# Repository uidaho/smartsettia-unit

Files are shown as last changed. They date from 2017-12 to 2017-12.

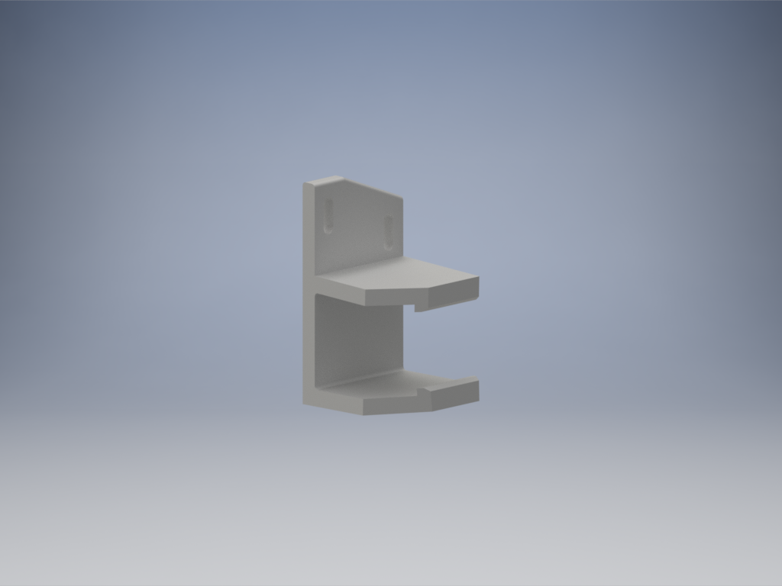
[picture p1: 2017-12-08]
3d_Parts/Limit_Switch_Brackets/Clip_Left_V2.png

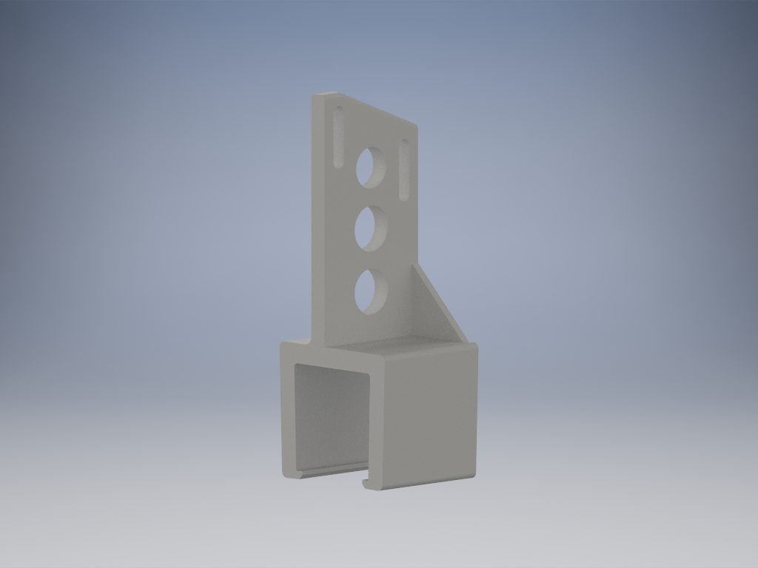
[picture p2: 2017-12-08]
3d_Parts/Limit_Switch_Brackets/Clip_Right.png

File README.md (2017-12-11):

# smartsettia-unit
Unit software for University of Idaho CS480 Capstone Project

## Instructions

### Raspberri Pi Setup
Download Raspbian 
[https://www.raspberrypi.org/downloads/raspbian/](https://www.raspberrypi.org/downloads/raspbian/)
unzip the file.

Follow these instructions
https://www.raspberrypi.org/documentation/installation/installing-images/README.md
or [download Rufus](https://rufus.akeo.ie/) and flash the image

Run `sudo raspi-config`

1. Change User Password – This step is **absolutly required!** Follow the on-screen directions to set a new password for you Pi. By default the password is set to `raspberry`, and the user is set to `pi`.

1. Under Networking
   * N1 Change Hostname to `Smartsettia-Unit` or another descriptive name
   * N2 Setup wifi. Enter 'AirVandalGuest' & `GoVandals!` to connect to guest network
      * Note: This will only work for the guest network. AirVandalGold requires additional setup
      * Wifi Settings can be configured with  `sudo nano /etc/wpa_supplicant/wpa_supplicant.conf`

1. (optional) Enable Boot to Desktop(default) or command line – Select whether to boot into desktop or simply the text console. The console mode will obviously boot faster, and you can type Startx to open the GUI. Booting to desktop may be easier for those more comfortable with Windows or Mac, though.
Internationalisation Options – Here you can adjust the timezone, keyboard layout, and language of your Pi. These changes take a while to be made, so be patient.

1. Localization - By default raspberian is in britain.
   * T1 Change Locale - By default raspberian is in britain.
      * Use the space key to enable `en_US.UTF-8`
      * Next menu choose `en_US.UTF-8` for the default language
   * T2 Change Timezonee - `US` > `Pacific-New` or your prefered timezone
      * Note: the smartsettia-unit script uses UTC time so the device timezone does not affect the opperation of this project

1. Interfacing Options
   * SSH - (optional) Enable if you need it. More secure if left disabled
   * I2C - Enable

1. Advanced Options
   * Expand Filesystem - This will ensure that the entire sd card is available to the system
  
1. Finish
1. Reboot `sudo reboot`

### Smartsettia Setup
Run the following commands
```bash
sudo apt update
sudo apt install git
git clone https://github.com/uidaho/smartsettia-unit.git
```
Change directory into the cloned folder.
`cd smartsettia-unit`

Run the setup script.
`sudo ./setup.sh -y`

## Running Smartsettia
For most situations and production the script is run and managed by the system. <br>
To check the status: `sudo systemctl status smartsettia.service` <br>
\* `status` can be replaced with the following commands: `stop`, `start`, `restart`

## Viewing Output
To view output
Follow current program output: `journalctl -u smartsettia.service -f` <br>
To see output since a date: <br>
\*  `journalctl -u smartsettia.service --since yesterday` <br>
\*  `journalctl -u smartsettia.service --since '1 hour ago'` <br>
To exit, press: `ctl + c`

For more options and controls for viewing logs: https://www.loggly.com/ultimate-guide/using-journalctl/

## Updating Smartsettia
When new code is pushed to github, you can update the device through this command <br>
``` bash
cd smartsettia-unit
./update.sh
```
Note you can add `-d` to pull and update on the development branch. `./update.sh -d`

## other program options
These commands are primarly focused for development purposes.
```
usage: main.py [-h] [-s] [-fw] [-d D] [-cd CD] [-npi] [-u UUID]

optional arguments:
  -h, --help            show this help message and exit
  -s, --single          Runs the program loop only once
  -fw, --fakewebcam     Use Fake webcam
  -d D                  Specify Domain. 0 prod, 1 brandon c9, 2 nick c9.
                        Default 0
  -cd CD                Specify custom Domain. This overrides all other domain
                        settings
  -npi, --notpi         Run as if this was not a raspberry pi. Disables GPIO
                        reading
  -u UUID, --uuid UUID  Use supplied UUID5 instead of generated uuid
```

`-s` or `--single` Runs all the internal tasks only once then exits

`fw` or `--fakewebcam` This pulls an image from a fast updating trafic camera when testing on a system without a physical camera

`-d D`  Used like `-d 2` This selects from a list of predefined urls for tesing on other development servers.

`-cd CD` Overrides server address to given address. `-cd https://httpbin.org` for example

`npi` or `notpi` Used when running on a system that does not have GPIO ports, aka hardware pins. This is used to disable GPIO outputs and simulates inputs for testing.

`-u UUID` or `-uuid UUID`  This is used to override the generated UUID number to what is provided. This can be used to replace a device and give it an existing identity. `-u "fdf9626a-65da-52ef-b43b-aed368471aa1"`

### References
https://learn.sparkfun.com/tutorials/setting-up-raspbian-and-doom#setup-raspbian

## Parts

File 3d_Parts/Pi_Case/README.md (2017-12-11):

# SmartSettia Device Enclosure
Instead of using the included STL, you can live edit the original at tinkercad.
https://www.tinkercad.com/things/jDfXh6rcM3P-smartsettia-device-enclosure/editv2

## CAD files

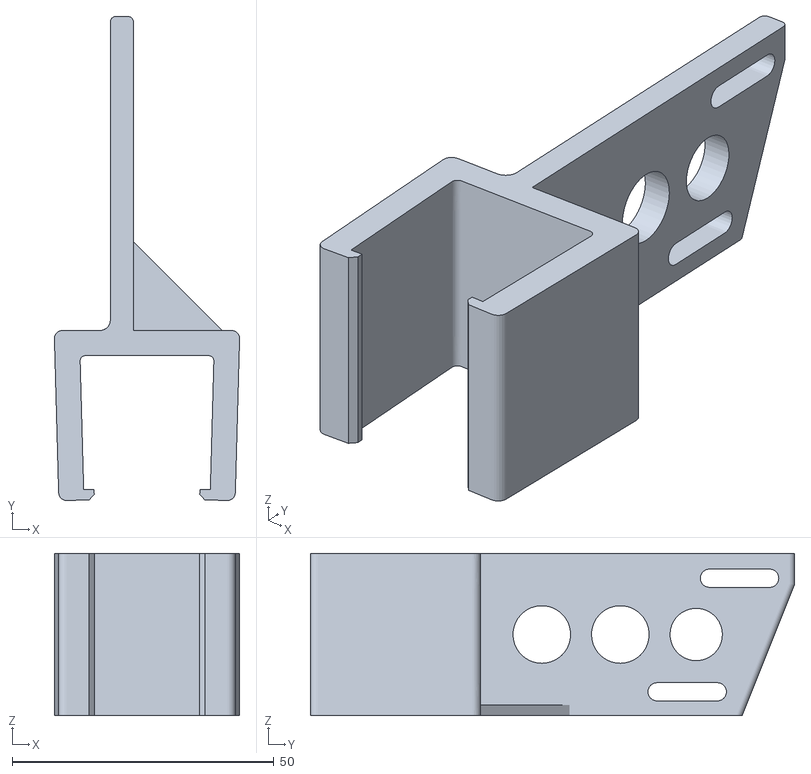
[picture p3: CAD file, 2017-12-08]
3d_Parts/Limit_Switch_Brackets/Clip_Right.stl
35.4 x 92.5 x 31.0

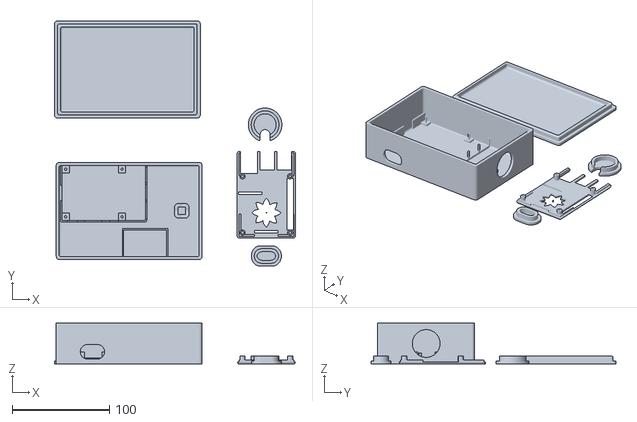
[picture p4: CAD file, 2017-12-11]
3d_Parts/Pi_Case/SmartSettia_Device_Enclosure.stl
248.0 x 252.5 x 42.0

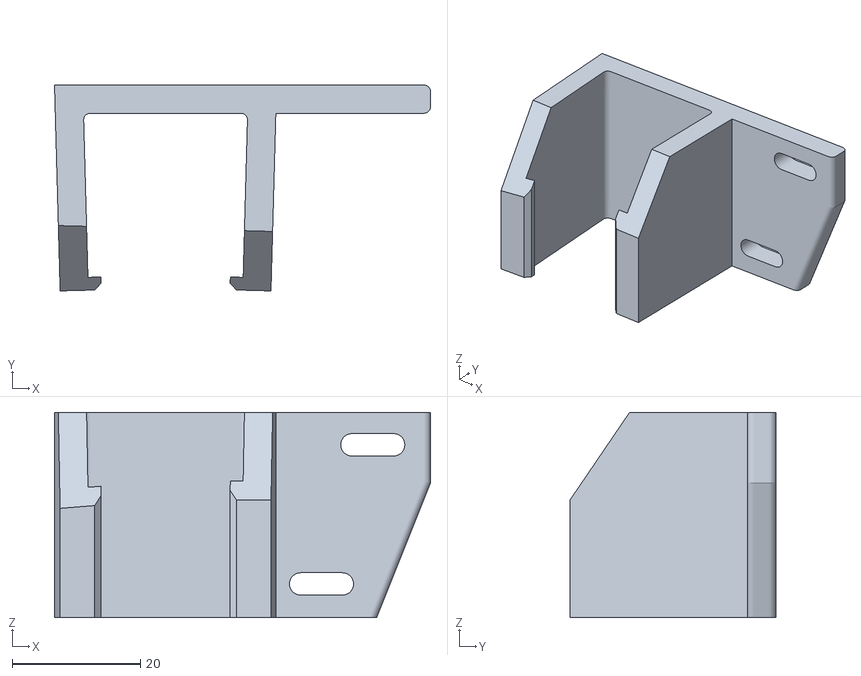
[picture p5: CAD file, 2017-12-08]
3d_Parts/Limit_Switch_Brackets/Clip_Left_V2.stl
58.6 x 32.1 x 32.0

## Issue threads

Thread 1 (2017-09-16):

Data variables brainstorming

Cyberzoid1, 2017-09-16:
Can you take a look at this and see if i'm missing any settings, or data that needs to be stored,sent, or received?
Doing some brainstorming.
https://github.com/uidaho/smartsettia-unit/blob/development/my_globals.py

brec9824, 2017-09-16:
I don't think you really need the name of the device since the pi serial number and key (essentially a password) will be enough to identify the device. Also how we have the schedule (not implemented yet) there might be multiple times throughout the day the cover opens and closes. So
`"Cover_schedual_open": "somedata",  # open time`
`"Cover_schedual_close": "somedata",}# close time`
will need to be an array(or something similar) of times.
Also webcam picture should be binary.

Cyberzoid1, 2017-09-16:
The name would probably only be used on a debugging webpage. No other practical use.

For the cover schedule, I thought we decided we were only doing a single open and close event?

brec9824, 2017-09-16:
Right now the database table for schedules allows for multiple open and close times for a day, but that schedule is used for every single day. So everyday of the week has the same schedule.

brandonjank, 2017-09-17:
The device should POST to https://smartsettia.com/api/ping with content type "application/json" a json formatted string, for now, like:
```json
{"token": "aSDf7986a89s7df87asd98f7dd", "uuid": "4dbc0776-9b44-11e7-abc4-cec278b6b50a", "version": "0.1.1", "name": "Unit Alpha", "hostname": "device.local", "ip": "192.168.1.213", "time": "YYYY-MM-DD HH:MM:SS", "status": "closed", "error_msg": "", "cpu_temp": "30", "temperature": "28", "humidity": "34", "light_in": "0", "light_out": "100", "switch_open": "0", "switch_closed": "1", "open_time": "HH:MM:SS", "close_time": "HH:MM:SS", "ping_time": "60"}
```

- token: think long random alphanumeric password
- uuid: A Version 1 UUID is a universally unique identifier that is generated using the MAC address of the computer on which it was generated.
- version: semantic versioning string of the device http://semver.org/
- name: what the unit thinks it's name is
- hostname: the /etc/hostname of the pi
- ip: the IPv4 of the pi
- time: the time and date formatted YYYY-MM-DD HH:MM:SS
- status: string value of the device's status. can be: opening, closing, open, closed, locked, error
- error_msg: string description of the error, empty if none
- cpu_temp: pi temperature in C
- temperature: temp sensor temperature in C
- humidty: humidity sensor. in 0-100 %
- light_in: light sensor inside awning. 0-100 %
- light_out: light sensor outside awning. 0-100 %
- switch_open: should be 1 when unit is in open position according to the limit switch.
- switch_closed: should be 1 when unit is in closed position accoring to the limit switch.
- open_time: the time the device should open HH:MM:SS
- close_time: the time the device should close HH:MM:SS
- ping_time: the interval between the the next time the device posts data in seconds.

The server with then validate the post request and respond with a json string which we can determine later.

Cyberzoid1, 2017-09-17:
All i'm getting back is the api page error
https://pastebin.com/NZ2zK1t1

brandonjank, 2017-09-17:
```php
<?php

use Illuminate\Support\Facades\Schema;
use Illuminate\Database\Schema\Blueprint;
use Illuminate\Database\Migrations\Migration;

class AddStatesToDevicesTable extends Migration
{
    /**
     * Run the migrations.
     *
     * @return void
     */
    public function up()
    {
        Schema::table('devices', function (Blueprint $table) {
            // token: think long random alphanumeric password
            $table->string('token')->nullable();
            // uuid: A Version 1 UUID is a universally unique identifier that is generated using the MAC address of the computer on which it was generated.
            $table->uuid('uuid')->nullable();
            // version: semantic versioning string of the device http://semver.org/
            $table->string('version')->nullable();
            // hostname: the /etc/hostname of the pi
            $table->string('hostname')->nullable();
            // ip: the IPv4 of the pi
            $table->ipAddress('ip')->nullable();
            // mac_address:
            $table->macAddress('mac_address')->nullable();
            // time: the time and date formatted YYYY-MM-DD HH:MM:SS
            $table->dateTime('time')->nullable();
            // timezone:
            $table->integer('timezone')->default(-8);
            // status: string value of the device's status. can be: opening, closing, open, closed, locked, error
            $table->enum('status', ['opening', 'closing', 'open', 'closed', 'locked', 'error'])->nullable();
            // error_msg: string description of the error, empty if none
            $table->text('error_msg')->nullable();
            // light_in: light sensor inside awning. 0-100 %
            $table->integer('light_in')->nullable();
            // light_out: light sensor outside awning. 0-100 %
            $table->integer('light_out')->nullable();
            // switch_open: should be 1 when unit is in open position according to the limit switch.
            $table->boolean('switch_open')->nullable();
            // switch_closed: should be 1 when unit is in closed position accoring to the limit switch.
            $table->boolean('switch_closed')->nullable();
            // open_time: the time the device should open HH:MM:SS
            $table->time('open_time')->default('08:00:00');
            // close_time: the time the device should close HH:MM:SS
            $table->time('close_time')->default('17:00:00');
            // ping_time: the interval between the the next time the device posts data in seconds.
            $table->integer('ping_time')->default(60);
            // TEMPORARY: these will get moved to sensors table
            // cpu_temp: pi temperature in C
            $table->integer('cpu_temp')->nullable();
            // temperature: temp sensor temperature in C
            $table->integer('temperature')->nullable();
            // humidty: humidity sensor. in 0-100 %
            $table->integer('humidty')->nullable();
        });
    }

    /**
     * Reverse the migrations.
     *
     * @return void
     */
    public function down()
    {
        Schema::table('devices', function (Blueprint $table) {
            $table->dropColumn('token','uuid','version','hostname','ip','mac_address','time','timezone','status','error_msg','light_in','light_out','switch_open','switch_closed','open_time','close_time','ping_time');
        });
    }
}

```

Closed 2017-10-08.

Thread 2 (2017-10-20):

Cover state machine error when simulated

Cyberzoid1, 2017-10-20:
When running under the `-npi` option where gipo is disabled and switches are simulated, moving substate is not getting the correct switch value and failing the move test.

```
--------------------------------------
fsm - Current state opening
Reading limit switches
        Current sensors open/close (0,1)
        Current server command:  open
Entered State: opening  Substate: ts1:RelayWait
Setting Relay to off
not pi:  True
        GPIO disabled
Reading limit switches
fsm - Next state opening
--------------------------------------

--- Uploading Status -----------------
Response code:  201
server command:  open
open 15:00:00   close 00:00:00
Status Update Successful
--------------------------------------
fsm - Current state opening
Reading limit switches
        Current sensors open/close (0,0)
        Current server command:  open
Entered State: opening  Substate: ts3:MovingTest
        Error: Cover did not move. Time now is: 1508486349.9
fsm - Next state error
--------------------------------------
fsm - Current state error
Reading limit switches
        Current sensors open/close (0,1)
        Current server command:  open
Entered State: Error
Reading limit switches
fsm - Next state closed
--------------------------------------

```

Cyberzoid1, 2017-10-20:
Should be fixed in commit 2534b75

Closed 2017-10-20.

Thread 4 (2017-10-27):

Power loss causes cover to move upon power restore

Cyberzoid1, 2017-10-27:
After power is restored from a power loss, the relay activates which activates the garage door opener.
This can lead to undesirable cover movement.

Will need to look into both hardware and software mitigations

Cyberzoid1, 2017-12-08:
Updated observations
Only happens when pluged in.
Does not happen at pi reboot or script starting.

I disconnected the signal line to the relay then unplugged and plugged in the unit. The cover did not move. But when the signal pin was reconnected. The relay was activated on power-cycle.
This can be due to a voltage glitch when the pi is powering up.

Possible solutions:
Add a capacitor to act as a glitch filter.
Or add a 10+k ohm pull down resistor to the pin.

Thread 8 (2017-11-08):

Directory restructure

Cyberzoid1, 2017-11-08:
I'm considering moving all my secondary python files to a library folder.
This will move much of the bulk out of the main directory to leave it a bit cleaner.
Slight technical issue when it comes to importing those files. But I found a way.

1) Is my current working directory. There are a few cache files and temp files but as you can see it is more cluttered.

2) Is the proposed structure
Mainly thinking on a end user standpoint.

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

Opinions?

brec9824, 2017-11-08:
If it isn't going to cause any issues for you I think 2 looks better from a user perspective.

brandonjank, 2017-11-14:
#2 looks better. I suggest that you follow the file structure style guide created by the makers of python at: http://docs.python-guide.org/en/latest/writing/structure/

Notice the folder name for the module is "sample", in our case it would be "smartsettia", "smartsettia-unit", or perhaps "unit".

An example github from a python dev can be found at: https://github.com/kennethreitz/samplemod

Cyberzoid1, 2017-12-12:
Implemented with commit c151b6f7fa5ccffa37d77158bff850b5a8136bf7

Closed 2017-12-12.

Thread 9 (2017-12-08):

Add .env file for setting device password

Cyberzoid1, 2017-12-08:
Currently the device password is set in the program and is publicly viewable.

Proposal would be to create a .env_example file that a user would copy to .env
This file would contain the following
device_password="device password"
uuid_override=""
Additional argument=""   << research if argparse can pull info during runtime to avoid reloading systemd service files

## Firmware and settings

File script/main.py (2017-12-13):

#!/usr/bin/python3
import time
import datetime
from os import path   # Used in checking webcam storage path
import os
import schedule    # scheduler library
import my_globals  # global variables
import argparse    # argument parsing
import helper_lib
import logging


# Logger: logging config   https://docs.python.org/3/howto/logging-cookbook.html
logger = logging.getLogger()
formatter = helper_lib.MyFormatter()           # sets format of the logs. Uses cusom class
logger.setLevel(logging.DEBUG)              # This essentially sets the highest global logging level

# Logger: create file handler which logs even debug messages
fh = logging.FileHandler('/var/log/smartsettia/smartsettia.log')
fh.setFormatter(formatter)      # set format
fh.setLevel(logging.WARNING)    # set level for file logging
logger.addHandler(fh)           # add filehandle to logger

# Logger: create console handle
ch = logging.StreamHandler()
ch.setFormatter(formatter)
ch.setLevel(logging.WARNING)    # set logging level for consol
logger.addHandler(ch)

# reduce logging level of libraries
logging.getLogger("schedule").setLevel(logging.WARNING)
logging.getLogger("requests").setLevel(logging.WARNING)
logging.getLogger("urllib3").setLevel(logging.WARNING)   # used by requests. cuts out 'connectionpool' logs


# https://stackoverflow.com/a/30493366
parser = argparse.ArgumentParser()
parser.add_argument('-s',  '--single',     action='store_true', help='Runs the program loop only once')
parser.add_argument('-fw', '--fakewebcam', action='store_true', help='Use Fake webcam')
parser.add_argument('-d',   type=int,      action='store',      help='Specify Domain. 0 prod, 1 brandon c9, 2 nick c9. Default 0', default="0")
parser.add_argument('-cd',  type=str,      action='store',      help='Specify custom Domain. This overrides all other domain settings', default=None)
parser.add_argument('-npi', '--notpi',     action='store_true', help='Run as if this was not a raspberry pi. Disables GPIO reading', default=False)
parser.add_argument('-u', '--uuid',     action='store', help='Use supplied UUID5 instead of generated uuid', default=None)
args = parser.parse_args() # parse args
my_globals.NOT_PI = args.notpi
DOMAIN_INDEX = args.d
DOMAIN_CUSTOM = args.cd
SINGLE_RUN = args.single
my_globals.FAKEWEBCAM = args.fakewebcam     # enable or disable fake webcam
UUID_CUSTOM = args.uuid          # custome uuid


# Import modules that need to be imported after environment setup
from helper_lib import generate_uuid, is_valid_uuid
from cover import gpio_cleanup
import remote_comm              # server communication module
import job_scheduling


def initialize():
    # Test if using a custom uuid and validate it. else use hardware uuid
    if (UUID_CUSTOM == None):
        generate_uuid()                 # generate uuid from hardware
    else:
        if is_valid_uuid(UUID_CUSTOM):
            print ("Custom UUID is: %s" % UUID_CUSTOM)
            my_globals.settings["uuid"] = UUID_CUSTOM
        else:
            print ("Invalid Custom UUID: %r" % str(UUID_CUSTOM))
            print ("          Format is: 'xxxxxxxx-xxxx-4xxx-xxxx-xxxxxxxxxxxx'")
            print ("Exiting")
            exit()
    
    my_globals.load_settings()      # load settings from file
    
    print ("Using fake webcam: ", my_globals.FAKEWEBCAM)
    print ("Not Pi flag: %s" % my_globals.NOT_PI)
    
    # Validate args.d (domain index) with possible domain indexes
    if (DOMAIN_INDEX >= 0 and DOMAIN_INDEX < len(my_globals.DOMAIN) and DOMAIN_CUSTOM == None):
        my_globals.update_url(my_globals.DOMAIN[DOMAIN_INDEX])
    elif (DOMAIN_CUSTOM != None):
        print("Using custom domain. Overriding url settings.")
        my_globals.update_url(DOMAIN_CUSTOM)
    else:
        print ("Error invalid domain index. Exiting")
        print ("To specify domain use '-d' <index>. from 0 to %d. For more info use '--help'" % (len(my_globals.DOMAIN)-1))
        exit()
    
    # check if /mnt/ramdisk exists else fallback to tmp directory
    if path.isdir(my_globals.settings["storage_dir"]) == 0:   # if path to directory exists
        logging.warning ("Ramdisk does not exist. Using /tmp/smartsettia")
        # This is undesirable for sdcard wear and writing speed compared to a ramdisk
        if not os.path.exists("/tmp/smartsettia/"):     # test if tmp directory exists
            os.makedirs("/tmp/smartsettia/")            # create directory
        my_globals.settings["storage_dir"] = "/tmp/smartsettia/"

    # log file setup for program start
    file=open(my_globals.settings["storage_dir"] + "error.log","a")
    file.write(str(datetime.datetime.now()))
    file.write("\tProgram start\n-------------\n")
    file.close()    

    remote_comm.register()
    
    # run the cover montitor a few times to let it syncronize
    job_scheduling.job_cover_monitor()
    job_scheduling.job_cover_monitor()
    
    # Setup job schedules
    job_scheduling.schedule_job_status()
    job_scheduling.schedule_job_sensors()
    job_scheduling.schedule_job_webcam()
    print ("--------------------------------------")


#Program start
print ("\nWelcome to Smartsettia!")
print ("Version: %s" % my_globals.version)
initialize()

# if single run run everything once
if SINGLE_RUN:
    print("Running single mode")
    schedule.run_all()      # run all jobs
    gpio_cleanup()
    exit()              # exit program

# watch dog setup.
# move to better spot later
# https://www.freedesktop.org/software/systemd/man/sd_notify.html#
# sdnotify: https://github.com/bb4242/sdnotify
import sdnotify
n = sdnotify.SystemdNotifier()
n.notify("READY=1")

# https://docs.python.org/2/library/signal.html
import signal

def signal_term_handler(signal, frame):
    print ('Recived signal: ', str(signal))
    n.notify("STOPPING=1")
    gpio_cleanup()
    exit(0)
    
while True and not SINGLE_RUN:
    schedule.run_pending()
    try:
        time.sleep(0.1)
    except KeyboardInterrupt as e:
        print("\nProgram exited by keyboard interrupt")
        n.notify("STOPPING=1")
        gpio_cleanup()
        exit()
    
    # watchdog
    try:
        n.notify("WATCHDOG=1")
    except Exception as e:
        print ("Error with watchdog: ", e)
        exit()  # debugging
    
    # test if program recieved a terminate command
    signal.signal(signal.SIGHUP , signal_term_handler) # 1
    signal.signal(signal.SIGINT , signal_term_handler) # 2
    signal.signal(signal.SIGQUIT, signal_term_handler) # 3
    signal.signal(signal.SIGABRT, signal_term_handler) # 6
    signal.signal(signal.SIGTERM, signal_term_handler) # 15

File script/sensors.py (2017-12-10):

import time
import platform         # test if pi for cpu temp
import my_globals
from subprocess import check_output
import logging

FAKE_SENSORS = my_globals.NOT_PI

# sensor simulate
sim_temperature = 0   # needs to be global to simulate Sensors
sim_cpuTemp = 35      # needs to be global to simulate Sensors

# update all sensor values
def update():
    my_globals.sensor_data["sensor_data"][0]["value"] = str(get_cpu_temp())
    my_globals.sensor_data["sensor_data"][1]["value"] = get_light()
    my_globals.sensor_data["sensor_data"][2]["value"] = str(get_light())  # TODO add light inner
    my_globals.sensor_data["sensor_data"][3]["value"] = str(get_Temp_Hum())
    logging.debug("Tempsensor [3]: %r"% my_globals.sensor_data["sensor_data"][3])
    logging.debug("Temp: %s\tCpu Temp: %s\tLight: %s" % (get_Temp_Hum(), get_cpu_temp(), get_light()))

# get temperature and humidity from sensor
def get_Temp_Hum():
    global sim_temperature
    sim_temperature = (sim_temperature + 1) % 50 + 50
    #print temperature
    return sim_temperature

# get ambiant light data
def get_light():
    light = 15
    return light

# get raspberri pi system temp
def get_cpu_temp():
    "Returns the CPU temerature based on architecture"
    if platform.machine() == "armv7l":
        return check_output(["/opt/vc/bin/vcgencmd measure_temp | cut -c6-9"], shell=True)[:-1].decode('utf-8')
    else:                   # either faking sensors and/or no armv7l architecture detected
        global sim_cpuTemp
        sim_cpuTemp = (sim_cpuTemp + 1) % 50 + 50
        return sim_cpuTemp

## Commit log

2017-09-14 Added Webcam framework
2017-09-14 using keyword arguments for sensor data
2017-09-15 Printing sensor_dat in main
2017-09-15 fixed 2 globals comma bug
    commas are the new ';'
    [my_globals.py]
2017-09-18 Remote: more work. Registration not working.
    [my_globals.py, remote_comm.py]
2017-09-18 cpu_temp rename & bugfix
    [sensors.py]
2017-09-18 Remote: bug fix. Now done
    [remote_comm.py]
2017-09-19 added webcam picture path
    As well as making the camera global so it doesn't have to re initialize
    Also added timer to see how long it take to take a picture
    [main.py, my_globals.py, webcam.py]
2017-09-20 Added run once program switch
2017-09-21 Added helper library & print error function,
    [helper_lib.py, main.py, remote_comm.py]
2017-09-22 Webcam picture upload uploads to server also added feature to download cat pics when no camera.
2017-09-22 Registration: test if success or fail
    [remote_comm.py]
2017-09-26 Added error checking to setting load/save
    [my_globals.py]
2017-09-27 Fake webcam switch '-fw' feature
2017-09-27 cleanup console logs
    Removed some print statements and made it more readable
2017-09-27 remote payload variable fix
    I thought already fixed this... twice now..
    [remote_comm.py]
2017-09-29 Improved webcam picture path detection. Globals fix
    Discovered that globalbs would not be updated when aliased or imported directly. Changed variabls to read directly from my_globals.py
    [main.py, remote_comm.py, webcam.py]
2017-09-29 Status & Sensor upload.
    Also some terminal logging formating
2017-10-08 single mode bug fix
    must of read the wrong api. its run-all() not run
    [main.py]
2017-10-08 Change how urls are loaded from settings.
    never load from file. always recalculate.
    This was causing some issues when you change the DOMAIN_INDEX but
    different url's are loaded from config file.
    [my_globals.py]
2017-10-08 url loading bug fix
    [my_globals.py]
2017-10-09 Added threading support
    didnt enable because it garbles up the terminal log
2017-10-09 Sensor temperature fix. now uploading
    [main.py, sensors.py]
2017-10-11 Cover GPIO framework. Added -npi option
    -npi or --notpi will disable gpio or other features that are unique to the raspberry pi
2017-10-15 Reworked the main structure of the transition state. GPIO work
    Still needs gpio testing which will be done next
    [cover.py, main.py]
2017-10-15 Limit switch GPIO working. State machine opening working
    still need to copy 'opening' to 'closing'
    still need to verify relay
2017-10-16 Sensors url change
2017-10-17 Sensor reframing
2017-10-18 sensor log outputing more info
2017-10-20 Fixed cover simulation bug
    [cover.py]
2017-10-20 Quick fix/patch for server_command overriding user on server.
    Will need to come up with a method of determining when server_command should be sent to override server.
    [remote_comm.py]
2017-10-20 Minor edit to main.py. Removed a couple of print lines
2017-10-20 Post merge fix of closed vs close comparison. Not directly comparing current state directly to server comand since the naming is slightly different. updated fsm_open() to match
    [cover.py]
2017-10-21 sensor url fix from merge conflict
    [my_globals.py]
2017-10-23 sensor url fix 2
    [my_globals.py]
2017-10-24 Print program version at start
2017-10-25 Removed status dictionary from sensor upload
2017-10-27 Webcam rework and overlay
    [webcam.py]
2017-10-27 Removed Test error message Also removed a setting not being used.
    [my_globals.py]
2017-10-27 Sensor cpu temp bug fix FAKE_SENSORS was staticly set to true and not based off of global settings
    [sensors.py]
2017-10-29 Only print remote debug print statements if not response code 200 or 201 Also added datetime print to "I'm working " heartbeat job
2017-10-29 Cover ensure relay pin is set low at start. This should be default but made it explicit here. Hopefully this will fix issue #4
    [cover.py]
2017-10-30 Save config bug fix Cover time will have to stay as a string then converted to datetime in cover:schedule function. json cannot serialize datatime
    [remote_comm.py]
2017-11-01 Fixed cpu_temp string conversion
    [sensors.py]
2017-11-07 Cover command override fix. Fix type in function name Slowed job rates
    [cover.py, main.py, remote_comm.py]
2017-11-07 Bug fix: NOT_PI always true. Artifact from merging
    [cover.py]
2017-11-10 Graceful exit by keyboard interrupt
2017-11-10 Untested service code framework.
2017-11-28 Logging update: sensors
2017-11-28 Logging update: myglobals, slight text change for webcam and sensors
2017-11-28 Logging formater class, removed old print_error functions & references
2017-11-28 missed a line in cover
    [cover.py]
2017-11-28 Bugfix, log reduction, Added req.text truncate after 2000 characters
    [remote_comm.py]
2017-11-28 Detect server 500 errors and sleep for 10 seconds Reduce log spam and other behaviors if there is a server error
    [remote_comm.py]
2017-11-29 Fakewbcam fix after scheduling rework
    [job_scheduling.py, main.py, my_globals.py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]
2017-11-29 Found some logging format errors in cover
    [cover.py]
2017-11-29 Fixed fsm_transition_state used prior to global declaration
    [cover.py]
2017-11-29 Cover button scheduling & gpio check
2017-11-29 Finished button code Still need to test & verify Still need to assign a pin
2017-11-30 Fixed bug where call function could not convert int to str in webcam
    [job_scheduling.py, webcam.py]
2017-11-30 rescheduling bugfix. typo and settings not updating
    [remote_comm.py]
2017-11-30 Cover: changed button pin to 7, logging improvements
2017-11-30 Cover button logic fix
    [cover.py, main.py]
2017-11-30 Enabled multithreading for long jobs, set cover button to run every 0.2 sec
2017-12-01 cover error_msg improved error messages
    [cover.py]
2017-12-05 error_msg reduction Commented out 'unexpected movement' in open/closed states. These accounted for all of the errors. Added slight delay for 'the unexpected movment' to settle.
    [cover.py]
2017-12-05 fix file error on failed request
    [remote_comm.py]
2017-12-07 Removed threading from status update Causing race conditions that are undesirable
2017-12-08 3d Bracket files
    [Clip_Left_V2.stl, Clip_Right.stl]
2017-12-10 service config & log directory fix
    [main.py, my_globals.py]
2017-12-11 add pi case stl and link to tinkercad original
    [SmartSettia_Device_Enclosure.stl]
2017-12-12 bugfix covertime always updating I believe that the old import of myglobal.settings was not updating when the globals were updated
    [remote_comm.py]
2017-12-13 Moved config and smartsettialog to user neutral location. Fixes travis build erroring from file does not exist
    [main.py, my_globals.py]
